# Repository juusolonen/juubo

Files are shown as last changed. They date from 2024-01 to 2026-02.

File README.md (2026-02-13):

# juubo ergonomic split keyboard

juubo keyboard is designed with [Ergogen](https://ergogen.cache.works/) following FlatFootFox's great guide found [here](https://flatfootfox.com/ergogen-introduction/).

## Contents

### V1

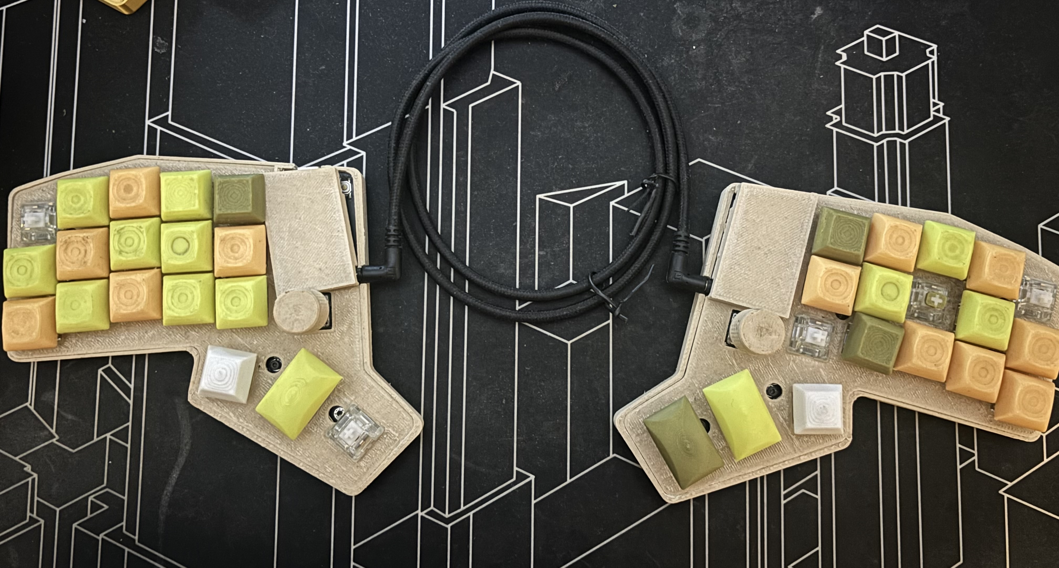
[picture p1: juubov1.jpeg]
Semi-retired V1

*Semi-retired V1*

V1 is a 36-key wired split keyboard, with rotary encoders on both side. It is wired with ProMicro RP2040 controllers, running with QMK. The pcb is designed so it can be made wireless with Nice!Nano controller and ZMK firmware (Firmware not provided, but V2 firmware can probably be modified eventually for V1 also). 

> `qmk` directory in this repo contains needed files to get the qmk firmware running. Note that the rotary encoders are not perfect so they might need some tweaking.
> Also note that the default keymap is a Colemak-DH with a Finnish hint.

### V2

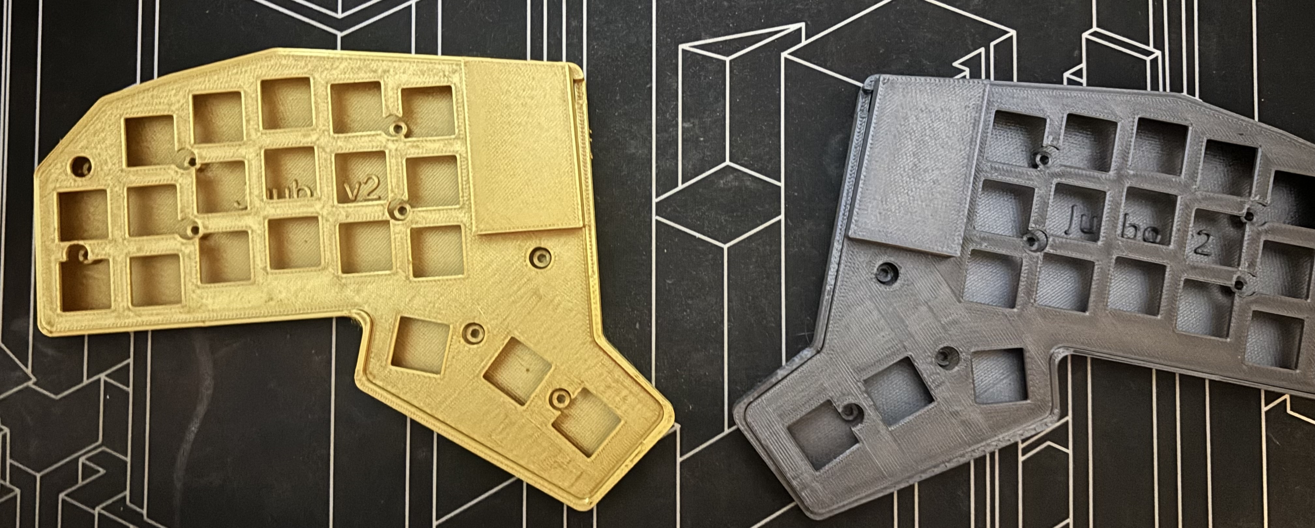
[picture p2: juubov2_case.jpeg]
Case V2

*3D printed case for the upcoming V2*

V2 is a 40-key wireless split keyboard and it does not have the rotary encoders anymore. Designer for Nice!Nano controller. Firmware will be built with ZMK eventually.

> [ZMK module for firmware](https://github.com/juusolonen/zmk-juubo-module) is not tested yet.

### ergogen

This directory contains the ergogen files used for V1. The mountinghole.js footprint is also used in V2, though.

**The files in /external-3d-models are not my own creation. They are just added to this repo just to keep all things in the same place**

## Bill of materials

#### Both versions
| Item | Count | Note/Model |
| --- | --- | --- |
| Reset button | 2 |SKQGABE010 |
| Socket for MCU | 2 | 315-43-112-41-003000 Note: optional |
| Header for MCU | 2 | EBBL-112-T-E Note: optional |
| Diodes | 36/40 | 1N4148W |
| Kailh MX hotswap sockets | 36/40 |  |
| MX switches | 36/40 |  |
| MX compatible keycaps | 36/40 | Note: Couple of 3d-models for printing available |
| M2x4x3 kurled insert nuts  | 12/18 | Optional: Needed for the printable case |
| M2 laptop style screws  | 12/18 | Optional: Needed for the printable case |

### V1 only

| Item | Count | Note/Model |
| --- | --- | --- |
| Promicro rp2040  | 2 | |
| Resistors | 2 | ERJ-2RKF4701X Note: only for other side |
| TRRS jack | 2 | PJ-320A |
| TRRS cable | 1 |  |
| EC11 rotary encoder | 2 | E.g. EC11E18244A5 |

#### V2 only

| Item | Count | Note/Model |
| --- | --- | --- |
| Nice!Nano  | 2 |  |
| Power switch  | 2 | SLW-66527511-SMT-TR|
| JST connector | 2 |S2B-PH-K-S |
| Battery | 2 | Rechargeable li-ion e.g. 301230 (This should fit under the MCU) |



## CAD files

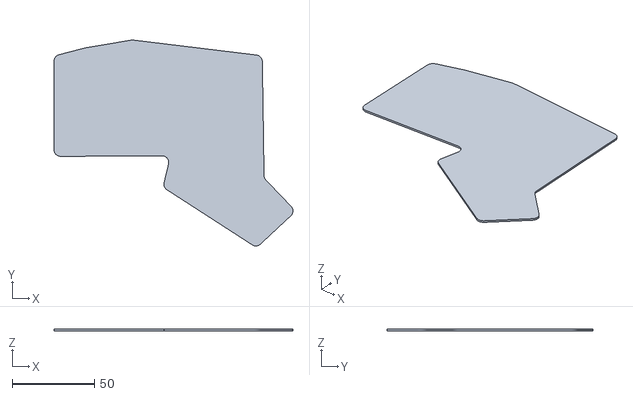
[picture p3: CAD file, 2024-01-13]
ergogen/bottom.stl
145.6 x 125.5 x 1.00

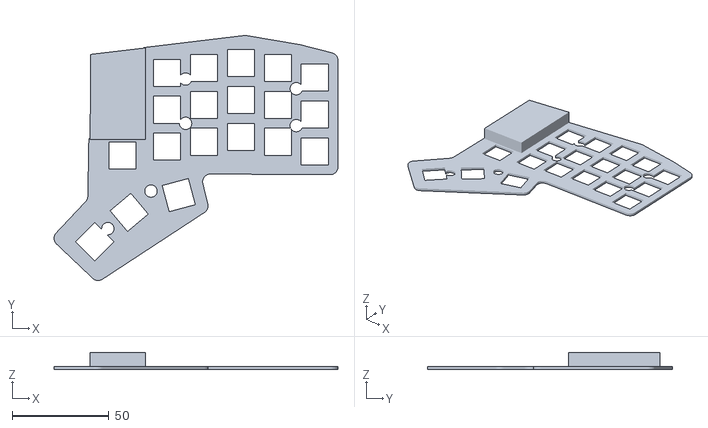
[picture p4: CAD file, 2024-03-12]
ergogen/output/cases/switchPlateWithStandRight.stl
146.7 x 126.6 x 9.00

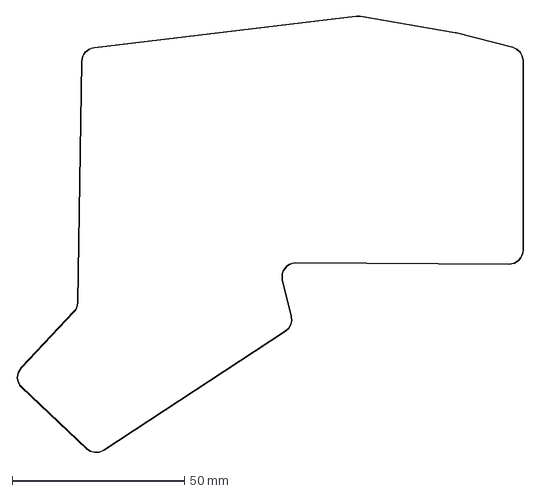
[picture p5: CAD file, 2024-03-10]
ergogen/output/outlines/boardRight.dxf
147.1 x 126.9 mm

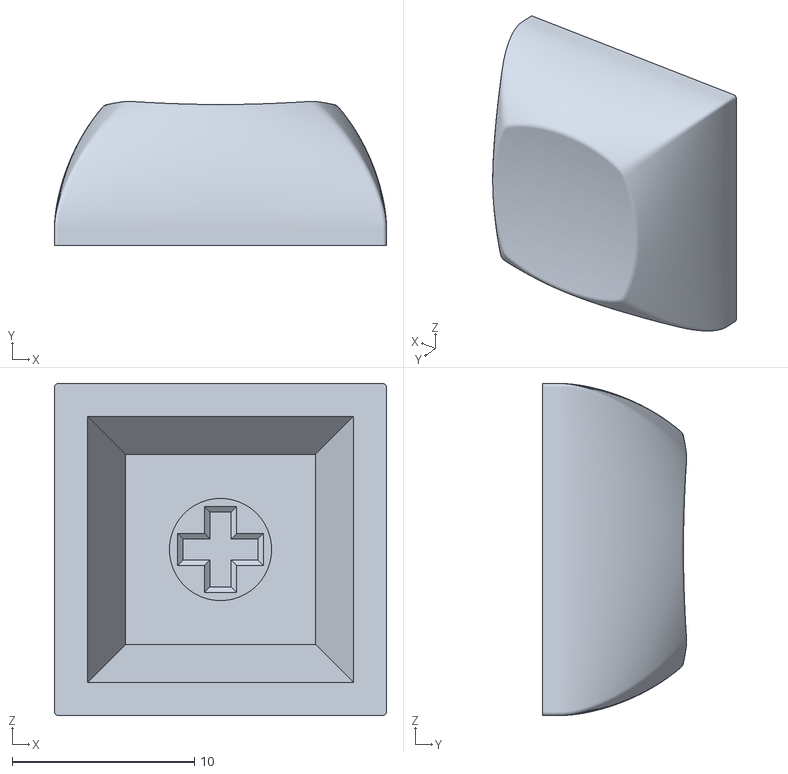
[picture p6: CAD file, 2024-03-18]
external-3d-models/DSA 1u (1).stl
18.2 x 7.91 x 18.2

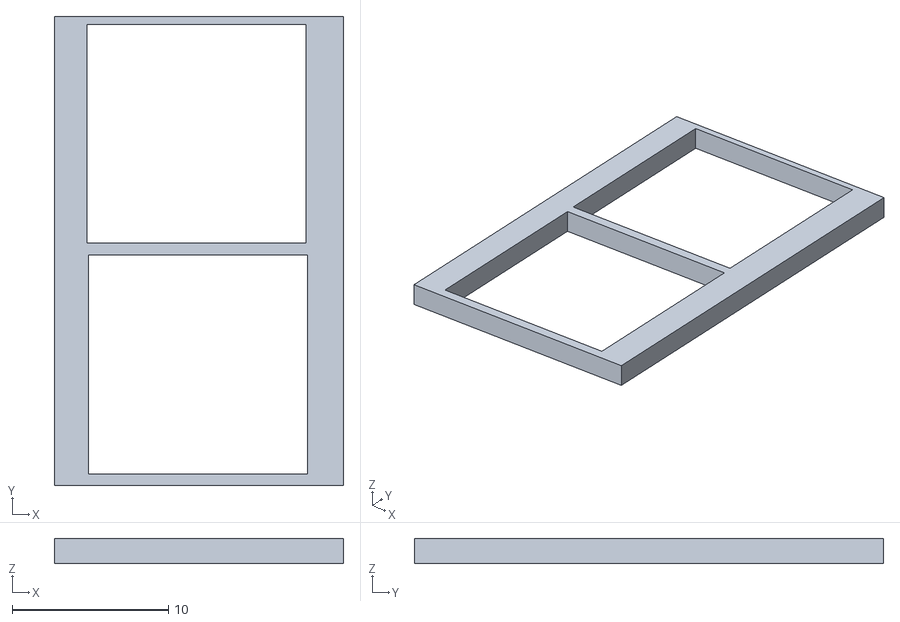
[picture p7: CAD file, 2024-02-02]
platetester.stl
18.5 x 30.0 x 1.60

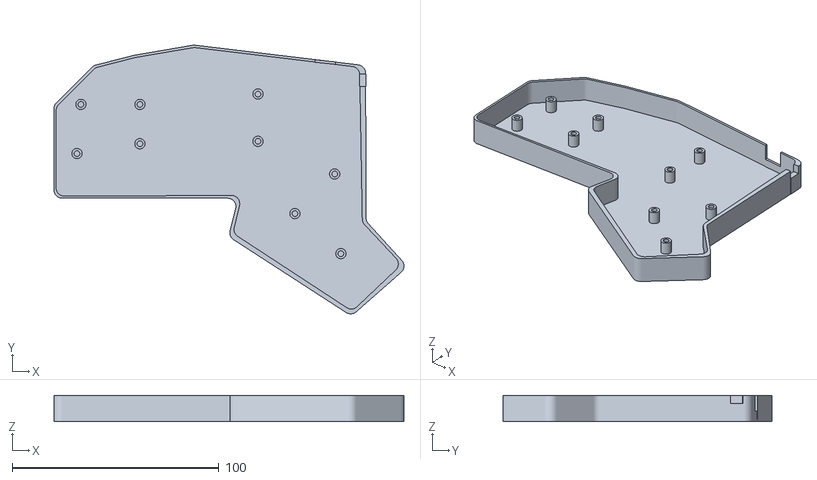
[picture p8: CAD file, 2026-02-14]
v2/case/case_left-12mm.stl
169.4 x 130.1 x 12.6

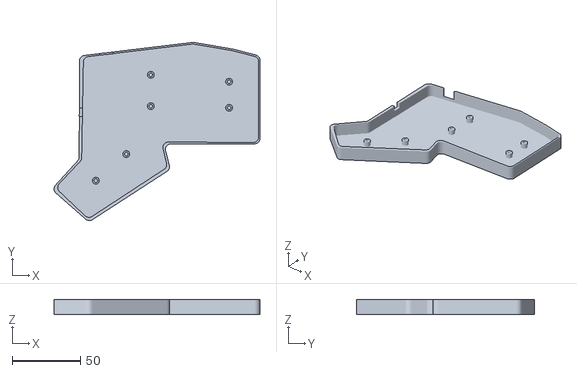
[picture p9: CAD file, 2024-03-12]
ergogen/output/cases/caseRight.stl
150.4 x 130.1 x 10.6

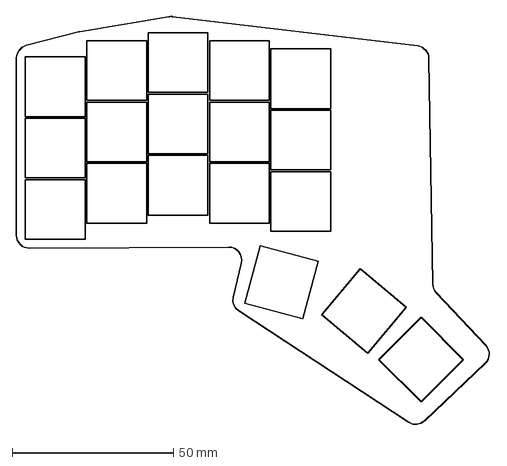
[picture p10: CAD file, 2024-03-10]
ergogen/output/outlines/combo.dxf
147.1 x 126.9 mm

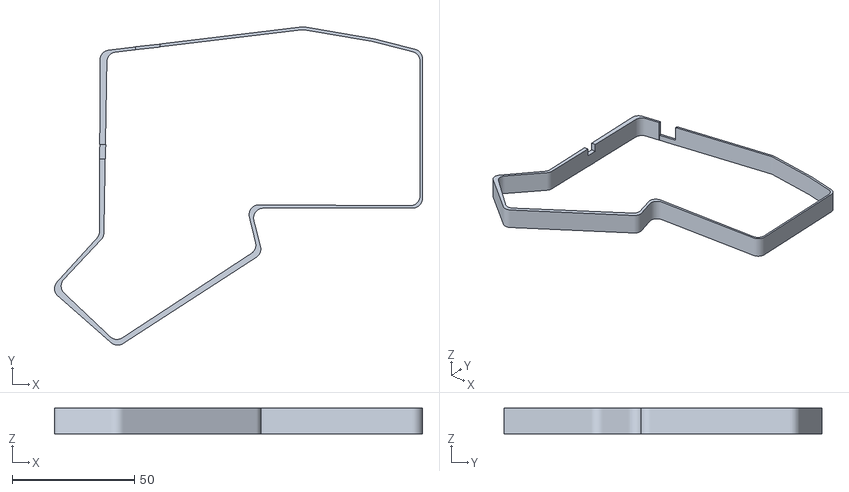
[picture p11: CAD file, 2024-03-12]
ergogen/output/cases/wallRight.stl
150.4 x 130.1 x 10.6

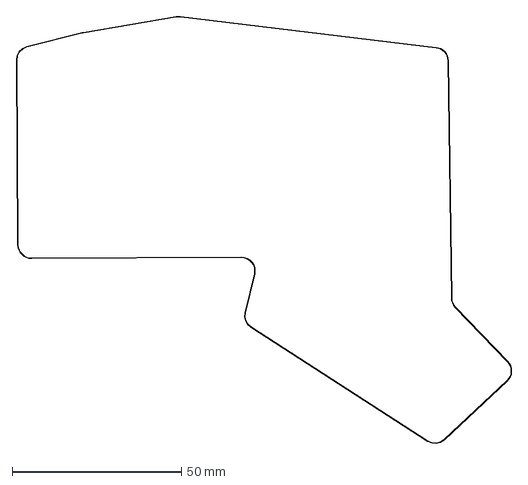
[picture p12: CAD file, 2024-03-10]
ergogen/output/outlines/boardForCase.dxf
146.1 x 126.4 mm

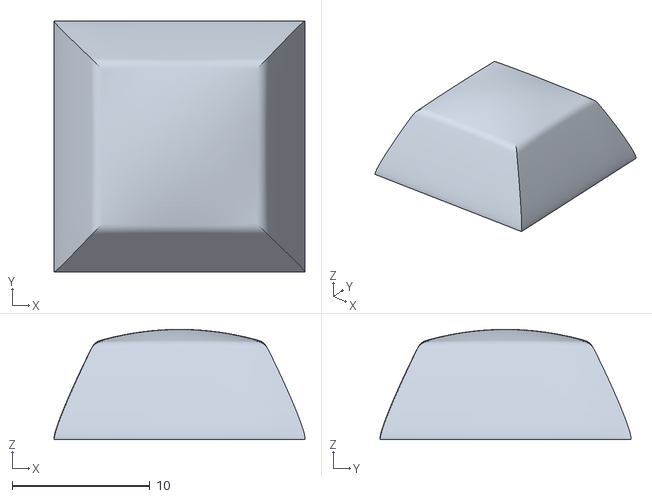
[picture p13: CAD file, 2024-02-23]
external-3d-models/DSA1_DOME.STL
18.2 x 18.2 x 8.00

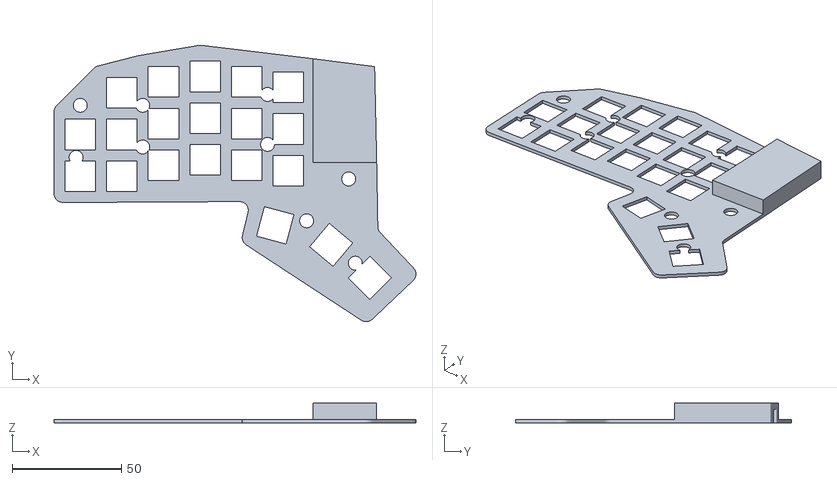
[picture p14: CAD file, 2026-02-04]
v2/case/switchPlate_with_MCU_cover_left.stl
165.7 x 126.6 x 9.00

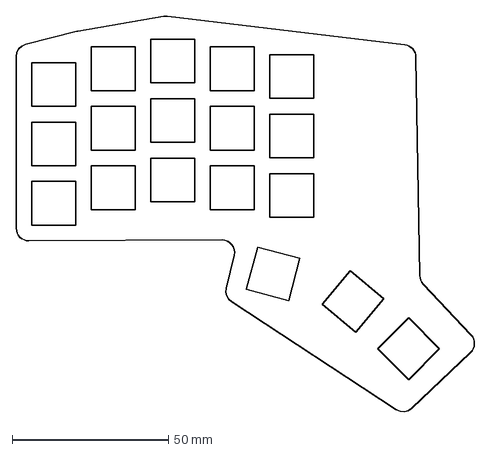
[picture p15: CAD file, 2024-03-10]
ergogen/output/outlines/switchPlate.dxf
147.1 x 126.9 mm

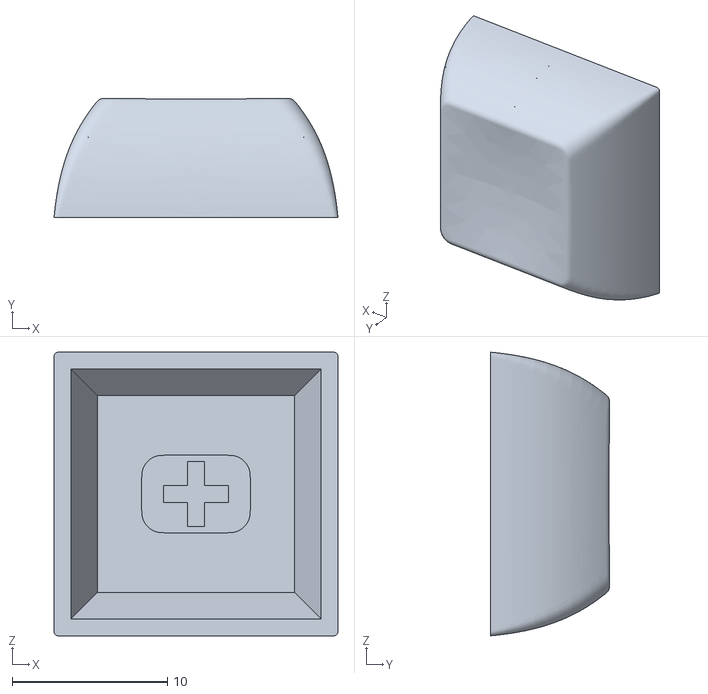
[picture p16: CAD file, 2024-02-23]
external-3d-models/DSA_Keycap_CherryMX.stl
18.3 x 7.69 x 18.3

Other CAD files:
external-3d-models/DSA_1u_clean_v5.stl
v2/case/case_right-12mm.stl
ergogen/output/cases/wall.stl
v2/case/case_left.stl
ergogen/output/cases/bottom.stl
ergogen/output/cases/bottomRight.stl
ergogen/output/cases/case.stl
ergogen/output/cases/stand.stl
ergogen/output/cases/switchPlate.stl
ergogen/output/cases/switchPlateWithStandLeft.stl
ergogen/output/cases/xlBottom.stl
ergogen/output/cases/xlBottomRight.stl
ergogen/output/outlines/board.dxf
ergogen/output/outlines/extraArea.dxf
ergogen/output/outlines/finalMount.dxf
ergogen/output/outlines/keys.dxf
ergogen/output/outlines/mounting.dxf
ergogen/output/outlines/raw.dxf
ergogen/output/outlines/standoff.dxf
ergogen/output/outlines/switches.dxf
ergogen/output/outlines/xlBoard.dxf
ergogen/output/outlines/xlBoardRight.dxf
external-3d-models/DSA 1.5.stl
external-3d-models/DSA 1u homing.stl
v2/case/case_right.stl
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

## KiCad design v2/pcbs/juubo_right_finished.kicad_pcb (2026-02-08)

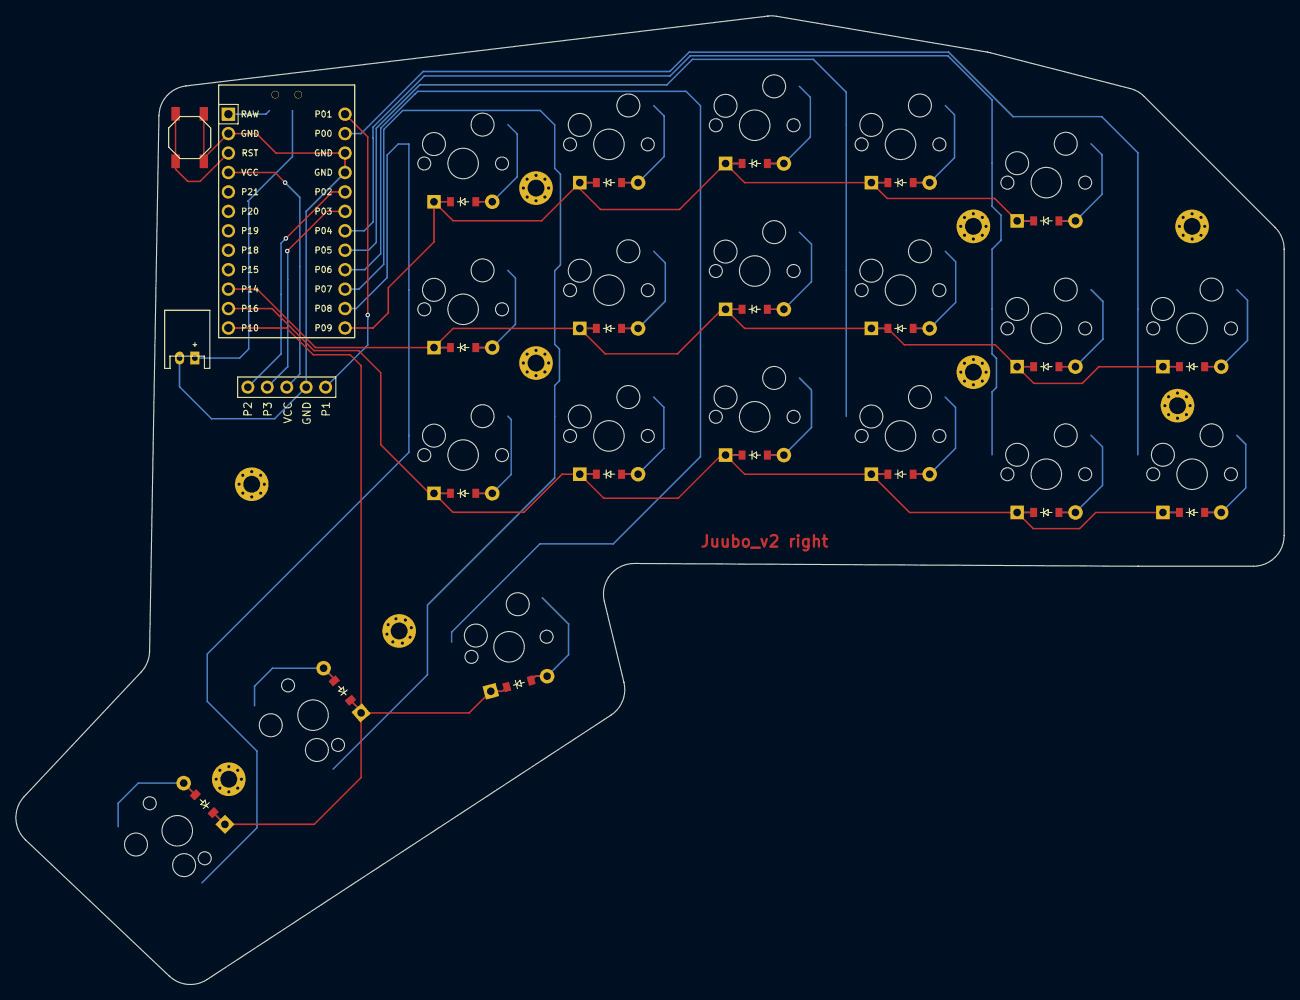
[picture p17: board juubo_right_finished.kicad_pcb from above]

Board: 2 copper layers, 165.7 x 126.6 mm, 54 parts (0 on the bottom side), 38 nets.

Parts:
B1: SW_TACT_ALPS_SKQGABE010
D1, D2, D3, D4, D5, D6, D7, D8, D9, D10, D11, D12, D13, D14, D15, D16, D17, D18, D19, D20: ComboDiode
DISP1: display_nice_view
JST1: JST_PH_S2B-PH-K_02x2.00mm_Angled
MCU1: ProMicro
S1, S2, S3, S4, S5, S6, S7, S8, S9, S10, S11, S12, S13, S14, S15, S16, S17, S18, S19, S20: MX
T1: SPDT_C128955
_1, _2, _3, _4, _5, _6, _7, _8, _9: MountingHole_2.2mm_M2_Pad_Via

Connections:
B+: JST1.1, T1.2
GND: B1.1, DISP1.4, JST1.2, MCU1.2, MCU1.15, MCU1.16
P0: MCU1.14, S1.1, S2.1
P1: DISP1.5, MCU1.13
P2: DISP1.1, MCU1.17
P3: DISP1.2, MCU1.18
P4: MCU1.19, S3.1, S4.1, S5.1
P5: MCU1.20, S6.1, S7.1, S8.1
P6: MCU1.21, S9.1, S10.1, S11.1, S18.1
P7: MCU1.22, S12.1, S13.1, S14.1, S19.1
P8: MCU1.23, S15.1, S16.1, S17.1, S20.1
P9: D5.1, D8.1, D11.1, D14.1, D17.1, MCU1.24
P10: D18.1, D19.1, D20.1, MCU1.12
P14: D2.1, D4.1, D7.1, D10.1, D13.1, D16.1, MCU1.10
P16: D1.1, D3.1, D6.1, D9.1, D12.1, D15.1, MCU1.11
RAW: MCU1.1, T1.1
RST: B1.2, MCU1.3
VCC: DISP1.3, MCU1.4
mirror_extra_cluster: D20.2, S20.2
mirror_index_bottom: D12.2, S12.2
mirror_index_home: D13.2, S13.2
mirror_index_top: D14.2, S14.2
mirror_inner_bottom: D15.2, S15.2
mirror_inner_home: D16.2, S16.2
mirror_inner_top: D17.2, S17.2
mirror_layer_cluster: D18.2, S18.2
mirror_middle_bottom: D9.2, S9.2
mirror_middle_home: D10.2, S10.2
mirror_middle_top: D11.2, S11.2
mirror_outer_bottom: D1.2, S1.2
mirror_outer_home: D2.2, S2.2
mirror_pinky_bottom: D3.2, S3.2
mirror_pinky_home: D4.2, S4.2
mirror_pinky_top: D5.2, S5.2
mirror_ring_bottom: D6.2, S6.2
mirror_ring_home: D7.2, S7.2
mirror_ring_top: D8.2, S8.2
mirror_space_cluster: D19.2, S19.2

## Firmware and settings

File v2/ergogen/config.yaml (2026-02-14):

units:
  kx: U
  ky: U
  px: kx + 4
  py: ky + 4
  dpx: kx + 6
  dpy: ky + 6
# M2 Screw Inserts
  screwSize: 1.4
  standoffSize: 2.5
  plateHole: 3.2
points:
  mirror: &mirror
    ref: matrix_inner_top
    distance: 7kx
  zones:
    matrix:
      anchor:
        shift: [120, -150]
      key:
        padding: ky
        spread: kx
      columns:
        outer:
          rows:
            mod:
              skip: true
            top:
              skip: true
          key:
            column_net: P21
            mirror.column_net: P0
        pinky:
          rows:
            mod:
              skip: true
          key:
            column_net: P20
            mirror.column_net: P4
        ring:
          rows.mod.skip: true
          key:
            stagger: 5
            column_net: P19
            mirror.column_net: P5
        middle:
          key:
            stagger: 2.5
            column_net: P18
            mirror.column_net: P6
        index:
          key:
            stagger: -2.5
            column_net: P15
            mirror.column_net: P7
        inner:
          key:
            stagger: -2.5
            column_net: P14
            mirror.column_net: P8
      rows:
        bottom:
          row_net: P9
          mirror.row_net: P16
        home:
          row_net: P10
          mirror.row_net: P14
        top:
          row_net: P16
          mirror.row_net: P9
    thumbs:
      key:
        padding: py
        spread: px
      anchor:
        ref: matrix_inner_bottom
        shift: [-6, -py-2]
      columns:
        layer:
          key:
            splay: -15
            column_net: P18
            mirror.column_net: P6
        space:
          key:
            rotate: -115
            shift: [4,-2]
            width: 1.5kx
            column_net: P15
            mirror.column_net: P7
        extra:
          key:
            rotate: -120
            shift: [2,-12]
            width: 1.5kx
            column_net: P14
            mirror.column_net: P8
      rows:
        cluster:
          row_net: P8
          mirror.row_net: P10
outlines:
  raw:
    - what: rectangle
      where: true
      size: [px, py]
  keys:
    - what: rectangle
      where: true
      size: [kx-0.5,ky-0.5]
  switches:
    - what: rectangle
      where: true
      size: 14
  board:
    - what: polygon
      operation: stack
      points:
        - ref: matrix_outer_home
          shift: [-0.5px-0.5,0.5py+0.5]
        - ref: matrix_pinky_top
          shift: [-0.5px-0.5,0.5py+0.5]
        - ref: matrix_ring_top
          shift: [-0.5px,0.5py+0.5]
        - ref: matrix_middle_top
          shift: [-0.1px,0.6py+0.5]
        - ref: matrix_inner_top
          shift: [1.7px+0.5,0.4py+0.5]
        - ref: thumbs_space_cluster
          shift: [-0.8px-0.5,0.5py+0.5]
        - ref: thumbs_layer_cluster
          shift: [3px+0.5, -0.2py]
        - ref: thumbs_layer_cluster
          shift: [2.25px+0.5,-1.4py-0.5]
        - ref: thumbs_extra_cluster
          shift: [1.3px,-2.3py-0.5]
        - ref: matrix_index_bottom
          shift: [0.1px-0.5,-0.7py-0.5]
        - ref: matrix_pinky_bottom
          shift: [-0.5px-0.5,-0.5py-0.5]
        - ref: matrix_outer_bottom
          shift: [-0.5px-0.5,-0.5py-0.5]
      fillet: 4
  boardRight:
    - what: polygon
      operation: stack
      points:
        - ref: mirror_matrix_outer_home
          shift: [-0.5px-0.5,0.5py+0.5]
        - ref: mirror_matrix_pinky_top
          shift: [-0.5px-0.5,0.5py+0.5]
        - ref: mirror_matrix_ring_top
          shift: [-0.5px,0.5py+0.5]
        - ref: mirror_matrix_middle_top
          shift: [-0.1px,0.6py+0.5]
        - ref: mirror_matrix_inner_top
          shift: [1.7px+0.5,0.4py+0.5]
        - ref: mirror_thumbs_space_cluster
          shift: [-0.8px-0.5,0.5py+0.5]
        - ref: mirror_thumbs_layer_cluster
          shift: [3px+0.5, -0.2py]
        - ref: mirror_thumbs_layer_cluster
          shift: [2.25px+0.5,-1.4py-0.5]
        - ref: mirror_thumbs_extra_cluster
          shift: [1.3px,-2.3py-0.5]
        - ref: mirror_matrix_index_bottom
          shift: [0.1px-0.5,-0.7py-0.5]
        - ref: mirror_matrix_pinky_bottom
          shift: [-0.5px-0.5,-0.5py-0.5]
        - ref: mirror_matrix_outer_bottom
          shift: [-0.5px-0.5,-0.5py-0.5]
      fillet: 4
  xlBoard:
    - what: polygon
      operation: stack
      points:
        - ref: matrix_outer_home
          shift: [-0.5dpx-0.5,0.5dpy+0.5]
        - ref: matrix_pinky_top
          shift: [-0.5dpx-0.5,0.5dpy+0.5]
        - ref: matrix_ring_top
          shift: [-0.5dpx,0.5dpy+0.5]
        - ref: matrix_middle_top
          shift: [-0.1dpx,0.6dpy+0.5]
        - ref: matrix_inner_top
          shift: [1.7dpx,0.4dpy+0.5]
        - ref: thumbs_space_cluster
          shift: [-0.8dpx-0.5,0.5dpy+0.5]
        - ref: thumbs_layer_cluster
          shift: [2.9dpx, -0.2dpy]
        - ref: thumbs_layer_cluster
          shift: [2.1dpx,-1.4dpy]
        - ref: thumbs_extra_cluster
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

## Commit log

2024-01-13 KiCAD for left
    [juubo_left.kicad_pcb]
2024-01-13 Add all ergogen files
    [board.dxf, combo.dxf, juubo_left.kicad_pcb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]
2024-01-13 Rename kicad folder to kicad_final
    [juubo_left.kicad_pcb]
2024-01-13 Add mounting holes to ergogen-generated pcb
    [juubo_left_no_res.kicad_pcb]
2024-01-13 Add resistors to ergogen, add bottom case
    [board.dxf, bottom.stl, case.stl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]
2024-01-13 Diode pads routed
    [juubo_left.kicad_pcb]
2024-01-13 Matrix traces
    [juubo_left.kicad_pcb]
2024-01-14 Fix board, tweak mountingholes
    [board.dxf, bottom.stl, case.stl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]
2024-01-16 Ready for routing
    [juubo_left.kicad_pcb]
2024-01-17 Left routed
    [juubo_left.kicad_pcb]
2024-01-18 Adjust and fix
    [juubo_left.kicad_pcb]
2024-01-19 Adjust holes
    [case.stl, juubo_left.kicad_pcb, mounting.dxf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]
2024-01-19 Switch plate things
    [case.stl, extraArea.dxf, finalMount.dxf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]
2024-01-21 Mount plate hole adjust & opening for usb
    [case.stl, extraArea.dxf, finalMount.dxf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]
2024-01-21 Poke hole for trrs
    [case.stl, wall.stl]
2024-01-21 Add right side
    [boardRight.dxf, bottomRight.stl, caseRight.stl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]
2024-02-02 random trash
    [juubo_left.kicad_pcb, juubo_left_backup.kicad_pcb, juubo_left_final.kicad_pcb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]
2024-02-02 test file
    [platetester.stl]
2024-02-05 Add switchplate stl
    [switchPlate.stl]
2024-02-12 Add mcu cover to switch plate left
    [case.stl, caseRight.stl, juubo_left_plate.kicad_pcb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]
2024-02-12 poke holes to mcu cover
    [case.stl, stand.stl, switchPlateWithStandLeft.stl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]
2024-02-13 slightly bigger holes
    [case.stl, switchPlateWithStandLeft.stl, wall.stl]
2024-02-21 Switchplate right done
    [juubo_left_plate.kicad_pcb, stand.stl, switchPlateWithStandLeft.stl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]
2024-02-21 adjust mcu cover
    [juubo_left_plate.kicad_pcb, switchPlateWithStandLeft.stl, switchPlateWithStandRight.stl]
2024-02-22 Adjust wall opening for case
    [case.stl, caseRight.stl]
2024-02-23 Add models, update readme
    [DSA 1.5.stl, DSA 1u homing.stl, DSA1_DOME.STL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]
2024-03-04 adjust left case 0.5mm bigger
    [case.stl]
2024-03-05 Adjust right side to fit pcb
    [caseRight.stl]
2024-03-05 couple of keycap models
    [DSA_1u_clean_v5.stl]
2024-03-10 Heighten case wall & plate thickness, left side
    [boardForCase.dxf, boardRight.dxf, bottom.stl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]
2024-03-10 Revert plate back to 1.6mm
    [switchPlateWithStandLeft.stl, switchPlateWithStandRight.stl]
2024-03-11 More height
    [case.stl, wall.stl]
2024-03-12 Adjust right plate
    [caseRight.stl, switchPlateWithStandRight.stl, wallRight.stl]
2026-01-20 Add qmk, gerber, kicad files
    [juubo_left.kicad_pcb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]
2026-01-21 V2 ergogen initial config, add new column, mounting points, start finetuning case and plate
2026-01-22 Adjust right side case&plate
2026-02-04 remove gerbers
    [juubo_left_final-B_Cu.gbr, juubo_left_final-B_Mask.gbr, juubo_left_final-B_Paste.gbr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]
2026-02-04 update readme, add files
    [case_left.stl, case_right.stl, juubo_left.kicad_pcb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]
2026-02-05 add nice_view, move jst to side, make hole to mcu cover for display
    [juubo_left _unrouted.kicad_pcb, juubo_right_unrouted.kicad_pcb]
2026-02-05 niceview to right side
    [juubo_right_unrouted.kicad_pcb]
2026-02-06 left side routed, add gerbers
    [juubo_left_finished-B_Cu.gbr, juubo_left_finished-B_Mask.gbr, juubo_left_finished-B_Paste.gbr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]
2026-02-08 fix right side thumb columns
    [juubo_right_unfinished.kicad_pcb]
2026-02-08 fix right half row nets
    [juubo_right_unfinished.kicad_pcb, juubo_right_unrouted.kicad_pcb]
2026-02-08 route right half, add gerbers
    [juubo_right_finished.kicad_pcb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]
2026-02-14 make cases 2mm higher (for storing battery underneath pcb)
    [case_left-12mm.stl, case_right-12mm.stl]
